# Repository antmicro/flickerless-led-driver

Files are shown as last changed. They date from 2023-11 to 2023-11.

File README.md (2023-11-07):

# Flickerless LED driver

Copyright (c) 2023 [Antmicro](https://www.antmicro.com) 

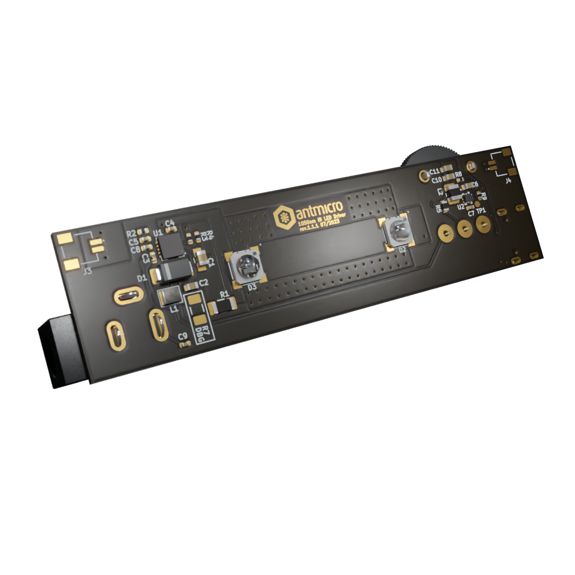
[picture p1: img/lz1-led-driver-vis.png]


## Overview 

This project contains open hardware design files for a PCB supporting a pair of infrared (IR) LEDs in an LZ1 LuxiGen package from OSRAM.
The PCB includes a flickerless LED driver that allows adjusting LED brightness with a potentiometer.
This design can be easily adopted to other LEDs and eventually can become a custom LED driver providing precise lighting for machine vision applications.
You can read more about flickerless LED driving in a dedicated blog [note](https://antmicro.com/blog/2022/02/machine-vision-with-flickerless-led-lighting/).
The design files were prepared in KiCad 6.x.

## Key features 

* LED current driver implemented with MPS/MP2483DQ-LF-P
* Designed for a pair of LZ1-00R802-0000
* Can be daisy-chained with multiple LEDs driven with a single driver

## Project structure

The main directory contains KiCad PCB project files, a LICENSE, and a README.
The remaining files are stored in the following directories:

* `lib` - contains the component libraries
* `img` - contains graphics for this README
* `assets` - contains visual assets for showcasing this design on [Open Hardware Portal](https://openhardware.antmicro.com).

## Usage

The project contains one PCB that can be configured as a primary or a secondary board, depending on the assembly variant. 
It is designed to be powered with 12V DC using a barrel jack.

### Primary board

This version contains the LED driver, all the connectors and a potentiometer. 

There are 3 connectors located on the primary board:
 
* USB-C - outputs 5V without data transfer, only to power an additional device, i.e. a microscope or a camera
* A barrel jack to power the whole circuit with 12V
* A 2-pin JST connector - to daisy chain boards with diodes in serial connection 

A rotary potentiometer is the element that provides control of diode brightness using the LED driver. 

### Secondary board 

This variant contains only the `LZ1` diodes, 2-pin connectors and resistors marked as secondary DP (`R10` and `R7`). 
It is powered and controlled by the primary board through JST connectors.

### Single board setup

To configure the primary board as a standalone, mount the `R7` Debug jumper in addition to `R11`. 

### Multi board setup

To daisy chain the boards, `R7` CANNOT be populated on the primary board and must be populated on secondary boards. 
`C_out` of one board must be connected to `A_in` of another one.
The design was made for up to 3 boards in a chain.

## Licensing

This project is published under the [Apache-2.0](LICENSE) license.

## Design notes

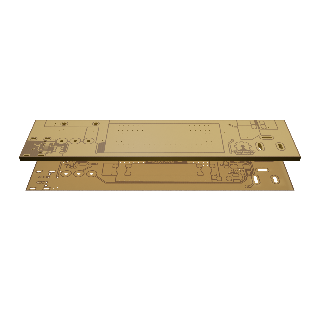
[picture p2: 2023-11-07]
assets/previews/layer1_thumbnail.webp

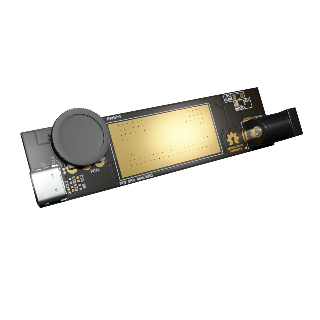
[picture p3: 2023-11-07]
assets/previews/leftT_thumbnail.png

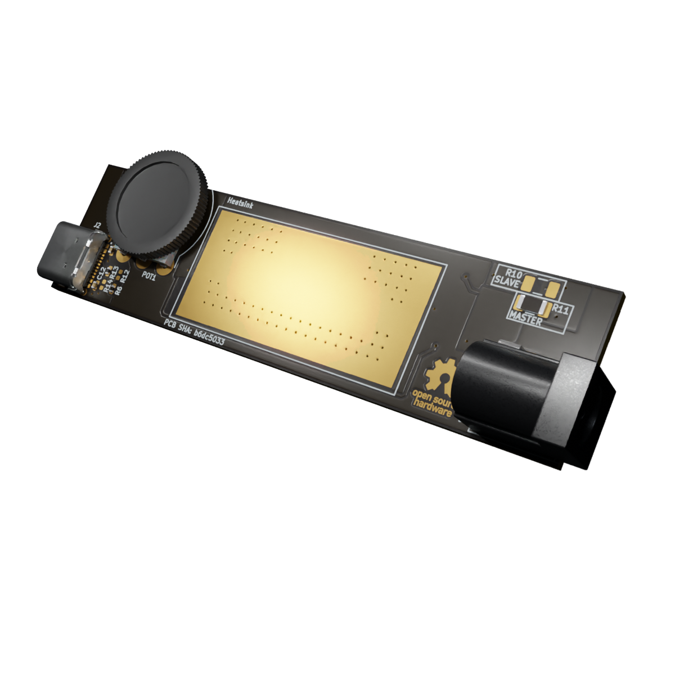
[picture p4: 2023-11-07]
assets/previews/rightT.webp

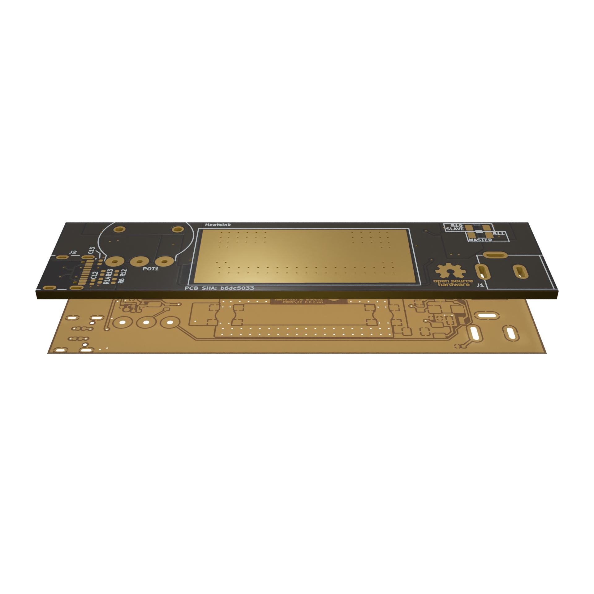
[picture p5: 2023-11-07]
assets/previews/stackup.png

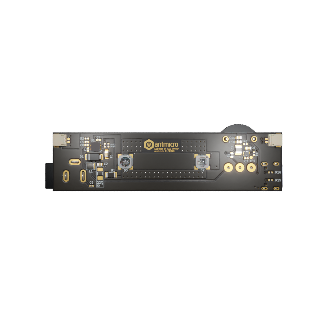
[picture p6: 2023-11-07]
assets/previews/orthoB_thumbnail.webp

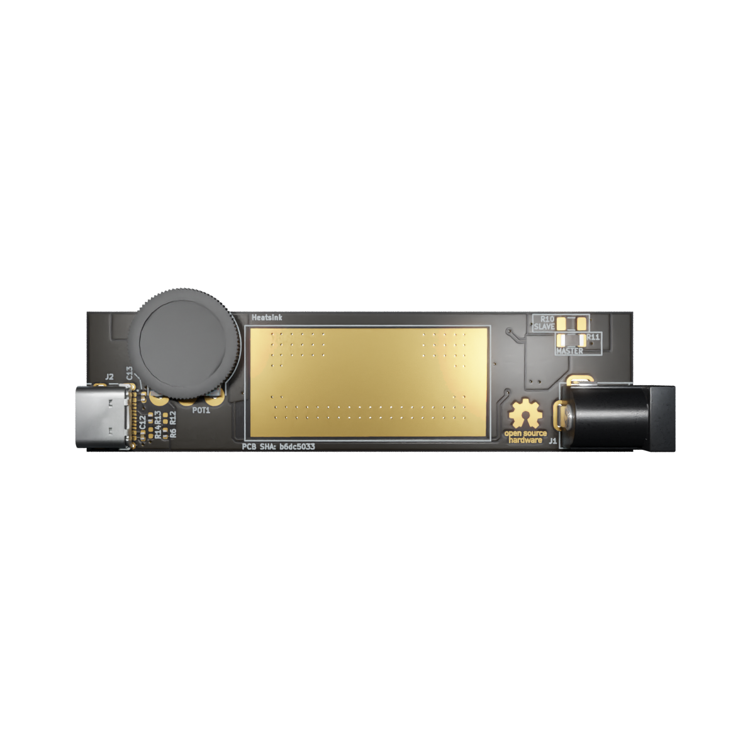
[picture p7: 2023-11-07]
assets/previews/orthoT.png

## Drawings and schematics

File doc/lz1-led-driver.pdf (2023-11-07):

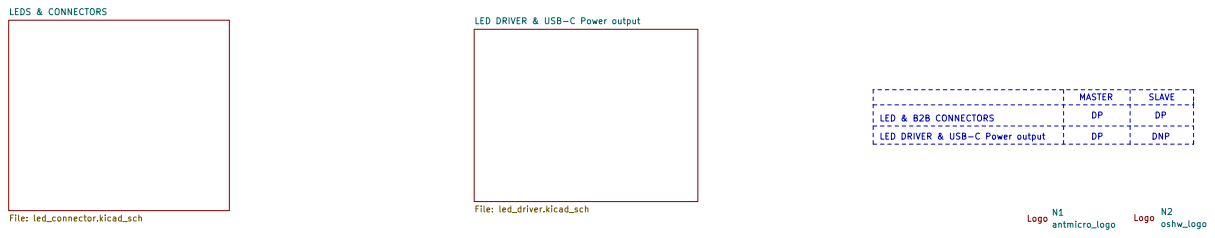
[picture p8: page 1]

LED DRIVER & USB-C Power output File: led_driver.kicad_sch

LED & B2B CONNECTORS | SLAVE DNP DP MASTER

LED DRIVER & USB-C Power output

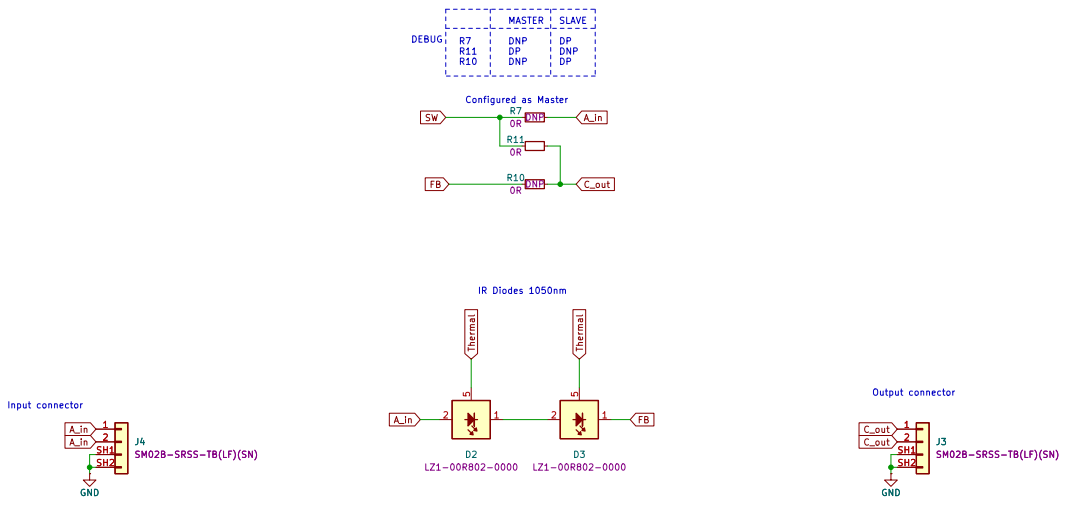
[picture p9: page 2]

J4SM02B-SRSS-TB(LF)(SN) 1

J3SM02B-SRSS-TB(LF)(SN) 1

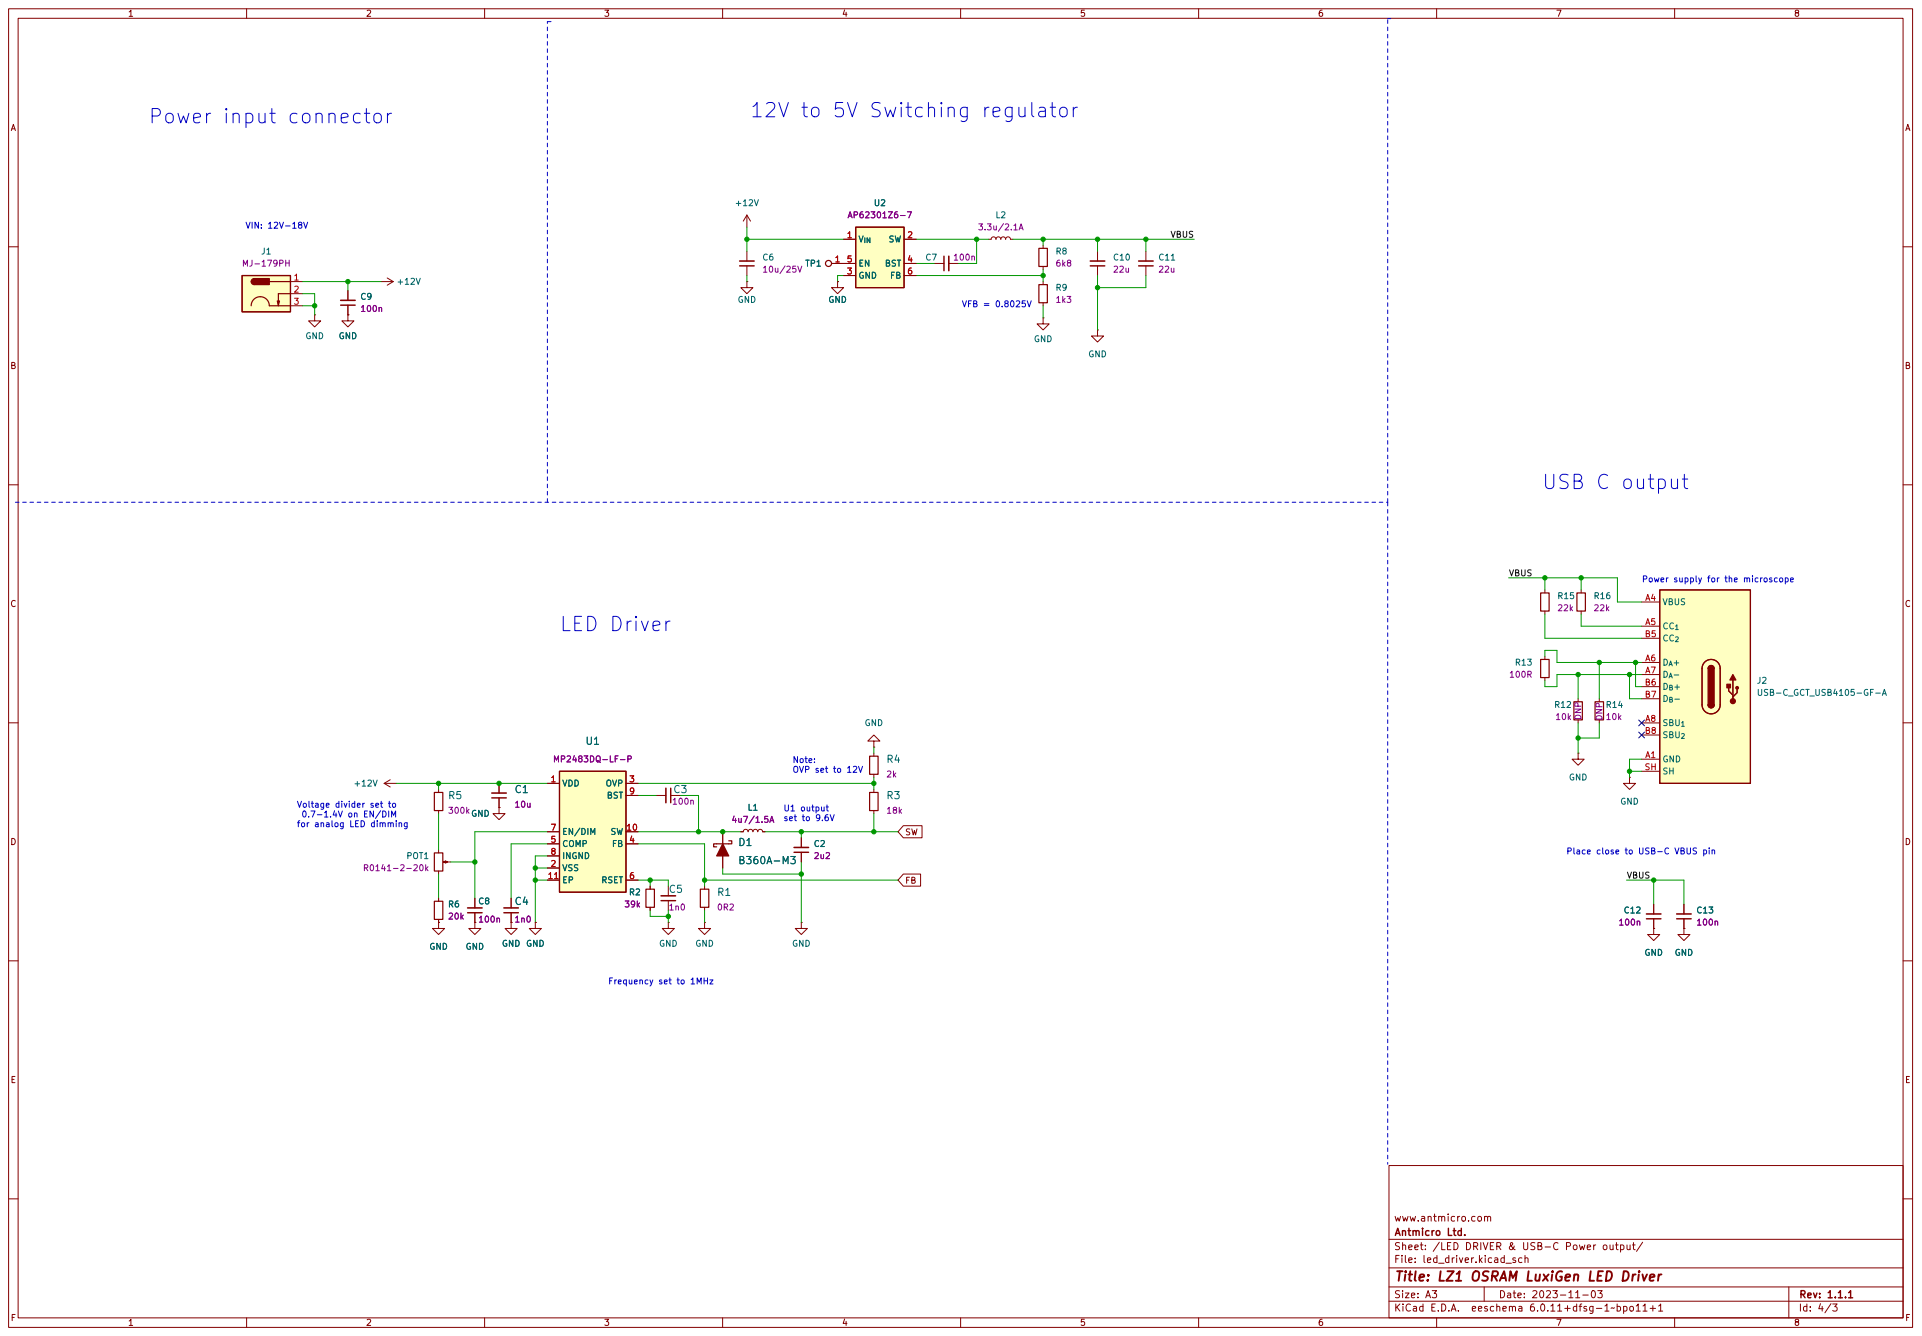
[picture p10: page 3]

Power supply for the microscope Place close to USB-C VBUS pin

Note: OVP set to 12V U1 output set to 9.6V

Voltage divider set to
for analog LED dimming

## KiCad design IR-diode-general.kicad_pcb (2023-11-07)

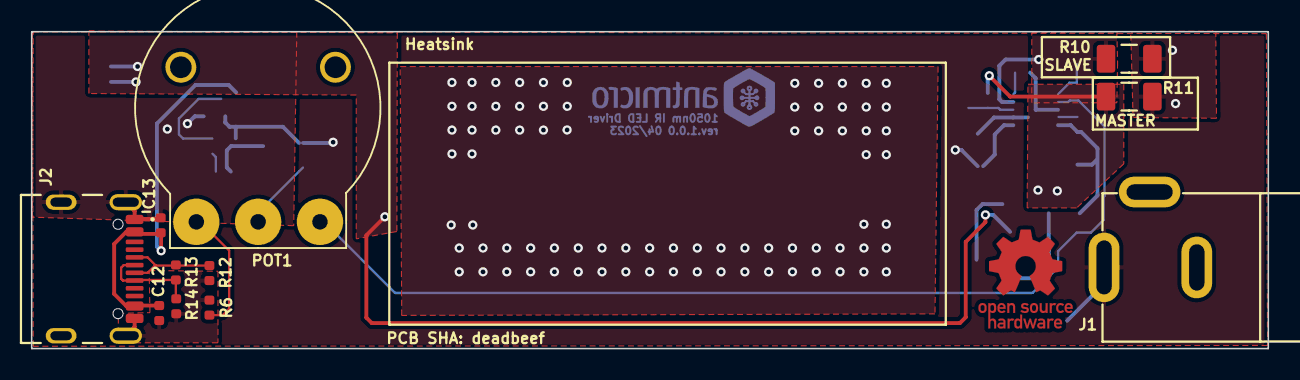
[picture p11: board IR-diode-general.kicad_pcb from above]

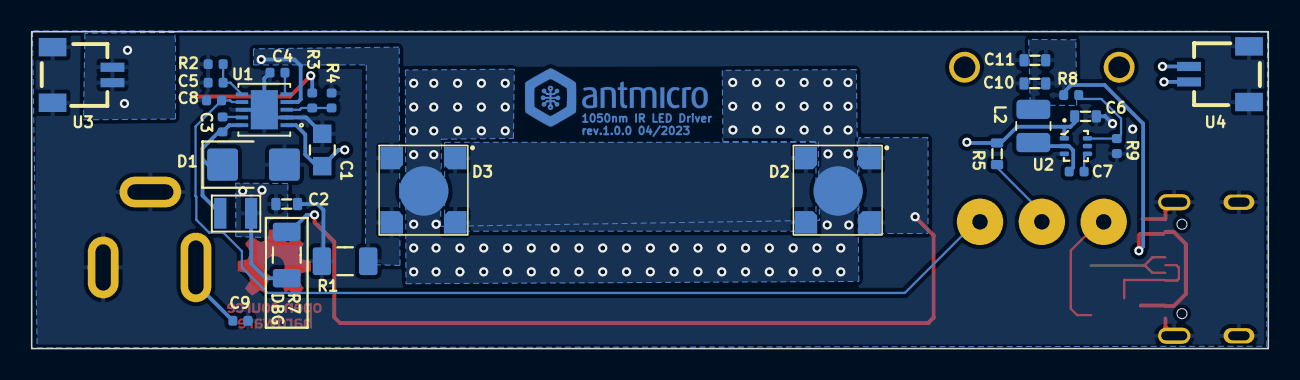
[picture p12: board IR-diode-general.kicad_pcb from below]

Board: 2 copper layers, 80.0 x 20.5 mm, 41 parts (29 on the bottom side), 22 nets.

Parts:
C1: C_10u_0805; 0805-cap
C2: C_2u2_0603; 0603-cap
C3, C7, C8, C9, C12, C13: C_100n_0402; C_0402_1005Metric
C4, C5: C_1n0_0402; 0402-cap
C6: C_10u_25V_0603; C_0603_1608Metric
C10, C11: C_22u_0603; C_0603_1608Metric
D1: B360A-M3; DO-214AC
D2, D3: LZ1-00R802-0000; LZ1-00R802_4EP_4.4x4.4
J1: BarrelJack_3167288; BarrelJack_3167288_Horizontal
J2: USB4105-GF-A; GCT_USB4105-GF-A
L1: SRP2512A-4R7M; SRP2512A-1R0M
L2: TFM252012ALMA3R3MTAA; L_1008_2520Metric
N1: antmicro_logo; antmicro-logo_scaled_12mm
N2: oshw_logo; oshw-logo
POT1: R0141-2-20k; Potentiometer_SRPassives_R0141-2_Horizontal
R1: R_0R2_1206; 1206-res
R2: R_39k_0402; 0402-res
R3: R_18k_0402; 0402-res
R4: R_2k_0402; R_0402_1005Metric
R5: R_300k_0603; 0603-res
R6: R_20k_0402; R_0402_1005Metric
R7, R10, R11: R_0R_1206; R_1206_3216Metric
R8: R_6k8_0402; 0402-res
R9: R_1k3_0402; R_0402_1005Metric
R12, R14: R_10k_0402; R_0402_1005Metric
R13: R_100R_0402; R_0402_1005Metric
U1: MP2483DQ-LF-P
U2: AP62301Z6-7; SOT-563
U3, U4: SM02B-SRSS-TB-LF-SN; JST_SM02B-SRSS-TB(LF)(SN)

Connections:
+12V: C1.2, C6.2, C9.2, J1.1, R5.2, U1.1 (VDD), U2.1 (VIN)
/LED DRIVER & USB-C Power output/VBUS: C10.2, C11.2, C12.2, C13.2, J2.A4 (VBUS), J2.A9 (VBUS), J2.B4 (VBUS), J2.B9 (VBUS), L2.2, R8.2
A_in: D2.2 (A), D2.3 (A), R7.1, U4.1, U4.2
C_out: R10.1, R11.1, U3.1, U3.2
FB: D3.1 (C), D3.4 (C), R1.2, R10.2, U1.4 (FB)
GND: C1.1, C2.1, C4.1, C5.1, C6.1, C8.1, C9.1, C10.1, C11.1, C12.1, C13.1, D1.A, J1.2, J1.3, J2.A1 (GND), J2.A12 (GND), J2.B1 (GND), J2.B12 (GND), J2.S1 (SHIELD), R1.1, R2.1, R4.2, R6.1, R9.1, R12.1, R14.1, U1.2 (VSS), U1.8 (INGND), U1.EPAD, U2.3 (GND), U3.3 (SHIELD), U3.4 (SHIELD), U4.3 (SHIELD), U4.4 (SHIELD)
unnamed: C3.1, D1.K, L1.1, U1.10 (SW)
unnamed: C3.2, U1.9 (BST)
unnamed: C4.2, U1.5 (COMP)
unnamed: C5.2, R2.2, U1.6 (RSET)
unnamed: C7.1, U2.4 (BST)
unnamed: C7.2, L2.1, U2.2 (SW)
unnamed: C8.2, POT1.3, U1.7 (EN/DIM)
unnamed: D2.1 (C), D2.4 (C), D3.2 (A), D3.3 (A)
unnamed: J2.A6 (D+), J2.B6 (D+), R13.1, R14.2
unnamed: J2.A7 (D-), J2.B7 (D-), R12.2, R13.2
unnamed: POT1.1, R6.2
unnamed: POT1.2, R5.1
unnamed: R3.2, R4.1, U1.3 (OVP)
unnamed: R8.1, R9.2, U2.6 (FB)
SW: C2.2, L1.2, R3.1, R7.2, R11.2
Thermal: D2.5 (T), D3.5 (T)

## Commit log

2023-03-30 MP2483DQ-LF-P converter
    [IR-diode-pcb.kicad_pcb, IR-diode-pcb.kicad_sch]
2023-11-07 Converter configured, pcb started
    [IR-diode-pcb.kicad_pcb, IR-diode-pcb.kicad_sch]
2023-11-07 Added USB-C and power barrel connector
    [IR-diode-pcb.kicad_sch]
2023-11-07 Rearranged project structure
    [IR-diode-general.kicad_pcb, IR-diode-general.kicad_sch, IR-diode-pcb.kicad_pcb]
2023-11-07 Add preliminary layout
    [IR-diode-general.kicad_pcb, IR-diode-general.kicad_sch]
2023-11-07 Changed R2
    [IR-diode-general.kicad_sch]
2023-11-07 Added notes on U1 configuration
    [IR-diode-general.kicad_sch]
2023-11-07 Changed the potentiometer to R0141-2-20k
    [IR-diode-general.kicad_sch]
2023-11-07 Changed the 12V-5V converter
    [IR-diode-general.kicad_sch]
2023-11-07 Layout and schematic updates
    [IR-diode-general.kicad_pcb, IR-diode-general.kicad_sch]
2023-11-07 Introduced hierarchical schematics
    [IR-diode-general.kicad_sch, LED_CONN.kicad_sch, led_driver.kicad_sch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]
2023-11-07 Layout tweaks
    [IR-diode-general.kicad_pcb, IR-diode-general.kicad_sch, led_driver.kicad_sch]
2023-11-07 Added pull down resistors on USB
    [IR-diode-general.kicad_pcb, IR-diode-general.kicad_sch, led_driver.kicad_sch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]
2023-11-07 Change pinout of B2B connectors
    [LED_CONN.kicad_sch]
2023-11-07 Add thermal pad label
    [LED_CONN.kicad_sch]
2023-11-07 Change diodes power rail labels
    [IR-diode-general.kicad_sch, LED_CONN.kicad_sch, led_driver.kicad_sch]
2023-11-07 Add 100n to VBUS, schematic cleanup
    [IR-diode-general.kicad_sch, led_driver.kicad_sch, usb_barrel.kicad_sch]
2023-11-07 B2B connectors symbol adjusted
    [IR-diode-general.kicad_pcb, IR-diode-general.kicad_sch, LED_CONN.kicad_sch]
2023-11-07 Finalized board layout
    [IR-diode-general.kicad_pcb, IR-diode-general.kicad_sch, LED_CONN.kicad_sch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]
2023-11-07 Improving power rail tracks and planes
    [IR-diode-general.kicad_pcb]
2023-11-07 Updated design rules
    [IR-diode-general-B_Adhes.gbr, IR-diode-general-B_CrtYd.gbr, IR-diode-general-B_Cu.gbr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]
2023-11-07 Power rail routing changes
    [IR-diode-general.kicad_pcb, led_driver.kicad_sch]
2023-11-07 Added signage
    [IR-diode-general.kicad_pcb, IR-diode-general.kicad_sch]
2023-11-07 Configured page properties
    [IR-diode-general.kicad_sch]
2023-11-07 Added OSHW marking
    [IR-diode-general.kicad_pcb, IR-diode-general.kicad_sch]
2023-11-07 Add BOM
    [IR-diode-general-BOM-populated.csv]
2023-11-07 Cleanup - remove generated files
    [IR-diode-general-BOM-populated.csv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]
2023-11-07 Update naming convention
    [led_connector.kicad_sch, led_driver.kicad_sch, lz1-led-driver.kicad_pcb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]
2023-11-07 Bump revision to 1.1. Update the PCB signage
    [led_connector.kicad_sch, led_driver.kicad_sch, lz1-led-driver.kicad_pcb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]
2023-11-07 README updates, board naming unification
    [lz1-led-driver.kicad_pcb]
2023-11-07 Correct sch logos. Update PCB from schematic
    [led_connector.kicad_sch, lz1-led-driver.kicad_sch]
2023-11-07 Refresh PCB
    [lz1-led-driver.kicad_pcb]
2023-11-07 Correct symbols and footprints with missing 3D models
    [led_connector.kicad_sch, lz1-led-driver.kicad_pcb, lz1-led-driver.kicad_sch]
2023-11-07 Refresh standardization on schematic and PCB
    [led_connector.kicad_sch, led_driver.kicad_sch, lz1-led-driver.kicad_pcb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]
2023-11-07 Updated Value fields in selected footprints
    [lz1-led-driver.kicad_pcb]
2023-11-07 Introduced schematic standardization
    [led_connector.kicad_sch, led_driver.kicad_sch, lz1-led-driver.kicad_pcb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]
2023-11-07 [50954] Added CC resistors and OHP assets, updated README
    [led_connector.kicad_sch, led_driver.kicad_sch, lz1-led-driver.kicad_pcb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]

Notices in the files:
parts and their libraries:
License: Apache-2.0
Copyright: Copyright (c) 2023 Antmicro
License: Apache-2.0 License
